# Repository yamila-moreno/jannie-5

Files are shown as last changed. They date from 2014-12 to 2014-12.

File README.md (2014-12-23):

jannie-5
========
Sensor-armed glove driven drone, for VII Piweek. More information, pics & videos [here](http://moduslaborandi.net/vii-piweek-jannie-5/).

This integration uses a slightly trimmed version of [python-ardrone](https://github.com/venthur/python-ardrone).

Hardware installation
---------------------

You will need:
- Parrot ARDrone 2.0
- Arduino Yún and power source (e.g. a 5V USB battery or an AC plug)
- [Triple Axis Accelerometer Breakout MMA8452Q](https://www.sparkfun.com/products/12756)
- [Force Sensitive Resistor](https://www.sparkfun.com/products/9375)
- [Flex Sensor](https://www.sparkfun.com/products/8606)
- 2 x 330 Ohm resistors
- 2 x 10 KOhm resistors
- A breadboard and wire
- A glove you can sew the sensors into

The Fritzing schematic of the circuit can be found inside the `docs` folder of the repo.

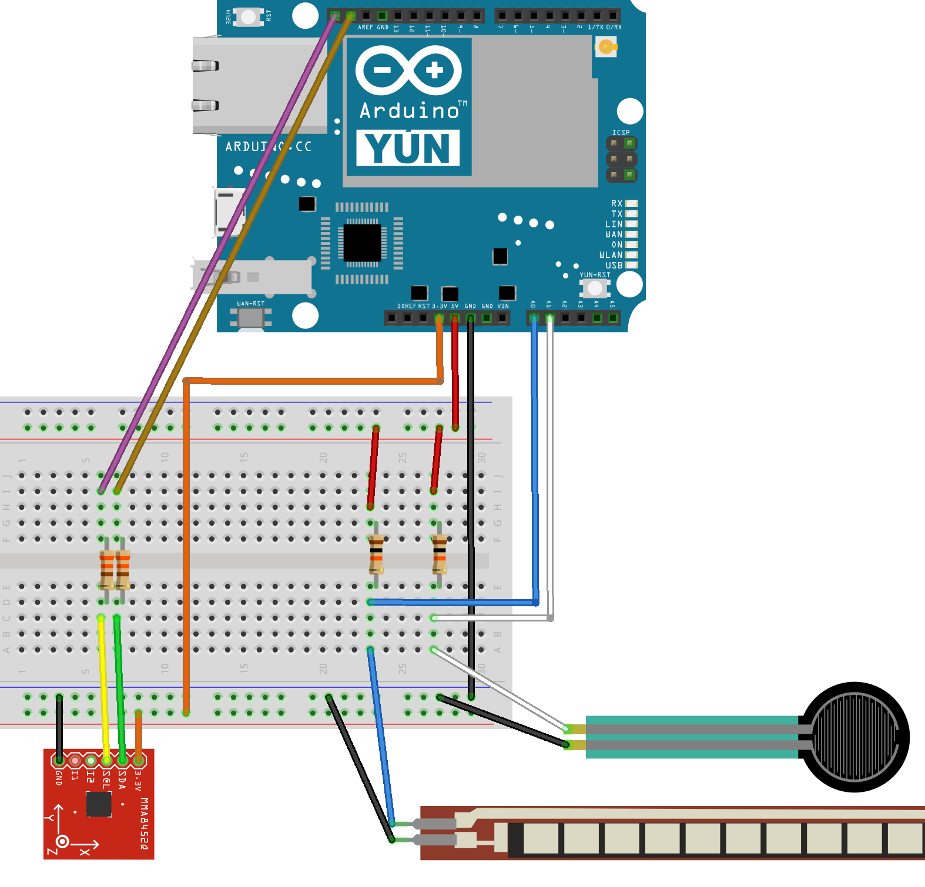
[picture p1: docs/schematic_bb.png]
Fritzing schematic


The sensors are meant to be sewed into the glove: for example, the Accelerometer to the palm of the hand, the Force Sensitive Resistor to the thumb and the Flex sensor the a finger. You will need long wires (for "maker" bonus points use conductive thread).

Software installation
---------------------

1. Clone this repo in order to retrieve the latest version of the files
2. Compile and upload the sketch `Ardruino.ino` to the Yún. You will need Arduino IDE 1.5.8+ and the [SFEMMA8452Q library](https://github.com/sparkfun/MMA8452_Accelerometer/tree/master/Firmware/libraries/SFE_MMA8452Q)
3. Copy the `src` folder to the `/root` folder of the Yún's Linino and install the python dependencies:

   ```
   opkg update
   opkg install distribute
   opkg install python-openssl
   easy_install pip
   pip install -r requirements.txt
   ```
4. Configure the Yun to automatically connect to the ARDrone WiFi (no encription!)
5. Test the library. If you grab the `libardrone-example.py` from the `examples` folder and put in into the same `src` directory, you will be able to test the library directly from the command line:

   ```
   python libardone-example.py
   ```
   Make sure the ARDrone is on and the Yún connected to the ARDrone WiFi
6. Start the API server on a console of the Yún or, even better, create a init script that runs the server headless:
       
   ```
   python ardrone_server.py
   ```
7. Test the API with the example:

   ```
   python bottle-example.py
   ```
8. If everything works, hold the glove and try to fly the ARDrone with it. Hints:
       - Push the Force Sensitive Resistor to take off / land
       - Flex the Flex Sensor to enable the Accelerometer control. Release it to hover.
       - Tilt the Accelerometer to move the drone in the horizontal plane

9. Enjoy :-)

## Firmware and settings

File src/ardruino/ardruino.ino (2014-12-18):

#include <Process.h>
#include <Wire.h> // Must include Wire library for I2C
#include <SFE_MMA8452Q.h> // Includes the SFE_MMA8452Q library

String url;
String cmd;

int pressPin = A1;
int pressValue;

int flexiPin = A0;
float flexiValue;
float degreesValue;

MMA8452Q accel; // Default MMA8452Q object create. (Address = 0x1D)

bool droneStarted = false;

void sendDroneAction(String action)
{
    Process p;
    url = "http://localhost:8080/" + action;
    cmd = "curl " + url;
    p.runShellCommand(cmd);
}

void setup()
{
    Serial.begin(9600);
    Serial.println("Initializing accelerometer: ");
    accel.init(); // Default init: +/-2g and 800Hz ODR
    Serial.println("Done!");
    Bridge.begin();
}

void loop()
{
    pressValue = analogRead(pressPin);
    Serial.print("pressValue: ");
    Serial.println(pressValue);

    if(pressValue > 400)
    {
        if(!droneStarted)
        {
            Serial.println("Take care, we are taking off");
            Serial.println("****************************");
            sendDroneAction("start");
            sendDroneAction("takeoff");
            droneStarted = true;
        }
        else
        {
            Serial.println("Fasten your belt, we are landing");
            Serial.println("********************************");
            sendDroneAction("land");
            sendDroneAction("stop");
            droneStarted = false;
            delay(5000);
        }
    }
    else
    {
        if(droneStarted)
        {
            flexiValue = analogRead(flexiPin);
            degreesValue = map(flexiValue, 250, 200, 0, 90); //from 0 to 90
            Serial.print("flexed degreesValue: ");
            Serial.println(degreesValue);
            if(degreesValue > 100)
            {
                accel.read();
                Serial.print("calculatedValues: ");
                Serial.print(accel.cx);
                Serial.print(" / ");
                Serial.print(accel.cy);
                Serial.print(" / ");
                Serial.println(accel.cz);
                if(accel.cx < -0.75)
                {
                    Serial.println("Adelante");
                    sendDroneAction("go_forward");
                }
                else if(accel.cx > 0.75)
                {
                    Serial.println("Atrás");
                    sendDroneAction("go_backward");
                }
                else if(accel.cy > 0.75)
                {
                    Serial.println("Izquierda");
                    sendDroneAction("go_left");

                }
                else if(accel.cy < -0.75)
                {
                    Serial.println("Derecha");
                    sendDroneAction("go_right");
                }
                else
                {
                    Serial.println("Hover");
                    sendDroneAction("hover");
                }

            }
            else
            {
                Serial.println("Order hover");
                sendDroneAction("hover");
            }
        }
    }
    delay(500);
}

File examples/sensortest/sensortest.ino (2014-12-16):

#include <Wire.h> // Must include Wire library for I2C
#include <SFE_MMA8452Q.h> // Includes the SFE_MMA8452Q library

int flexiPin = A0;
int flexiValue;
String flexiValues = "";

int pressPin = A1;
int pressValue;
int degreesValue;
String pressValues = "";

MMA8452Q accel; // Default MMA8452Q object create. (Address = 0x1D)
float xAccel;
float yAccel;
float zAccel;
String accelerationValues = "";
float cxAccel;
float cyAccel;
float czAccel;
String calculatedValues = "";

void setup(){
    Serial.begin(9600);
    Serial.println("Initializing accelerometer: ");
    accel.init(); // Default init: +/-2g and 800Hz ODR
    Serial.println("Done!");
}

void loop(){
    // TEST
    //letters = letters + "hola" + "y adios";
    //letters = letters + "b" + "c";
    //letters = letters + 1234;

    // FLEXOMETER
    flexiValue = analogRead(flexiPin);
    degreesValue = map(flexiValue, 250, 200, 0, 90);
    flexiValues = flexiValues + "flexiValue: " + flexiValue + " / degreesValues: " + degreesValue;
    Serial.println(flexiValues);
    flexiValues = "";
    // PRESSURE
    pressValue = analogRead(pressPin);
    pressValues = pressValues + "pressValue: " + pressValue;
    Serial.println(pressValues);
    pressValues = "";
    // ACCELEROMETER
    accel.read();
    xAccel = accel.x;
    yAccel = accel.y;
    zAccel = accel.z;
    accelerationValues = accelerationValues + "accelerationValues: " + xAccel + " / " + yAccel + " / " + zAccel;
    Serial.println(accelerationValues);
    accelerationValues = "";
    cxAccel = accel.cx;
    cyAccel = accel.cy;
    czAccel = accel.cz;
    calculatedValues = calculatedValues + "calculatedValues: " + cxAccel + " / " + cyAccel + " / " + czAccel;
    Serial.println(calculatedValues);
    calculatedValues = "";
    delay(500);
}

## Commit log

2014-12-14 Add very simple deploy script
    Arduino Yún only has a very old git version
2014-12-16 Add sensortest simple sketch
    Pressure, flexometer and accelerometer
2014-12-17 COMMIT FOR REVERT
    Test to make routes with slashes. take/off.
    [ardruino.ino]
2014-12-17 Fix accelerometers triggers
2014-12-22 Add docs files and schematic
    [schematic.fzz]
2014-12-22 Add schematic png
2014-12-22 Update schematic png
2014-12-22 Change wrong wire color
    [schematic.fzz]
